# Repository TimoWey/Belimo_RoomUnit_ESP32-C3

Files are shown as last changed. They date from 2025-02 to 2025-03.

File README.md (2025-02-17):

# Belimo RoomUnit ESP32-C3

This project reads Temperature, Humidity, and CO2 levels from a Belimo Room Unit sensor using a Seeed XIAO ESP32-C3 and publishes the data via MQTT.

## Hardware Requirements

- Seeed XIAO ESP32-C3 board (https://wiki.seeedstudio.com/XIAO_ESP32C3_Getting_Started/)
- Belimo Room Unit sensor
- Power supply (USB or external)
- Connecting wires

## Wiring

Connect the Belimo Room Unit to the ESP32-C3 as follows:

| Belimo Signal | ESP32-C3 Pin | ADC Channel |
|---|---|---|
| Temperature | GPIO2/A2 | ADC2 |
| Humidity | GPIO3/A3 | ADC3 |
| CO2 | GPIO4/A4 | ADC4 |
| GND | GND | - |

## Software Setup

### Prerequisites

1. Install ESP-IDF (Espressif IoT Development Framework)
2. Clone this repository
3. Navigate to the project directory

### Configuration

1. Configure the WiFi and other project settings using:
```bash
idf.py menuconfig
```

Under "Example Configuration":
- Set WiFi SSID
- Set WiFi Password

2. Update the following parameters in `main/main.c` according to your setup:
```c
#define MQTT_BROKER_URL "mqtt://192.168.0.68"    // Your MQTT broker IP/hostname
#define MQTT_PORT 1883                           // Your MQTT broker port
#define MQTT_TOPIC_TEMP "sensors/temperature_2"  // MQTT topic for temperature
#define MQTT_TOPIC_HUMIDITY "sensors/humidity_2" // MQTT topic for humidity
#define MQTT_TOPIC_CO2 "sensors/co2_2"          // MQTT topic for CO2
```

3. Optional settings you can modify:
- `LED_BLINK_ENABLED`: Set to `true` to enable status LED blinking
- `FILTER_SIZE`: Number of samples for reading averaging (default: 16)
- `SAMPLE_INTERVAL`: Time between samples in ms (default: 100)

4. Flash to your device:

```bash
idf.py -p [PORT] flash
```
```bash
idf.py monitor
```

## MQTT Data Format

The device publishes JSON data to three topics:

1. Temperature (sensors/temperature):

```json
{"voltage": 1.23, "temperature": 24.5}
```

2. Humidity (sensors/humidity):

```json
{"voltage": 1.23, "humidity": 50.0}
```

3. CO2 (sensors/co2):

```json
{"voltage": 1.45, "humidity": 45.2}
```

{"voltage": 1.67, "co2": 850.0}

## Sensor Ranges

- Temperature: 0°C to 50°C
- Humidity: 0% to 100%
- CO2: 0 to 2000 ppm

## LED Indicator

The onboard LED (GPIO10) can be enabled for status indication by setting `LED_BLINK_ENABLED` to `true` in the code.

## Troubleshooting

1. If the device fails to connect to WiFi:
   - Check your WiFi credentials
   - Ensure the device is within range of your WiFi network
   - Monitor the serial output for connection status

2. If MQTT publishing fails:
   - Verify your MQTT broker is running
   - Check the broker URL and port
   - Ensure your network allows MQTT traffic

## License

This project is open-source and available under the MIT License.

## Contributing

Feel free to submit issues and pull requests to improve this project.

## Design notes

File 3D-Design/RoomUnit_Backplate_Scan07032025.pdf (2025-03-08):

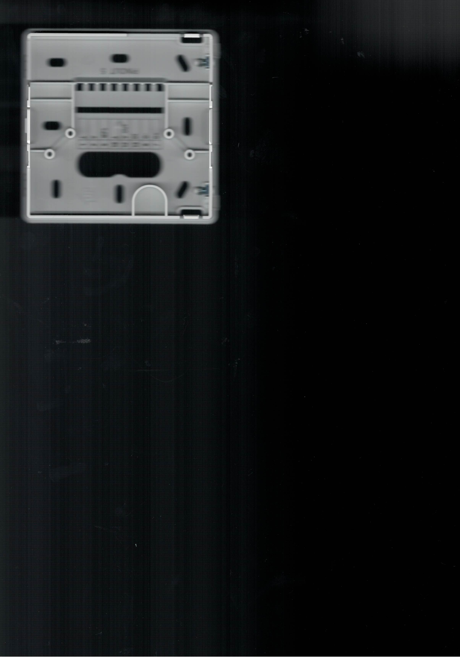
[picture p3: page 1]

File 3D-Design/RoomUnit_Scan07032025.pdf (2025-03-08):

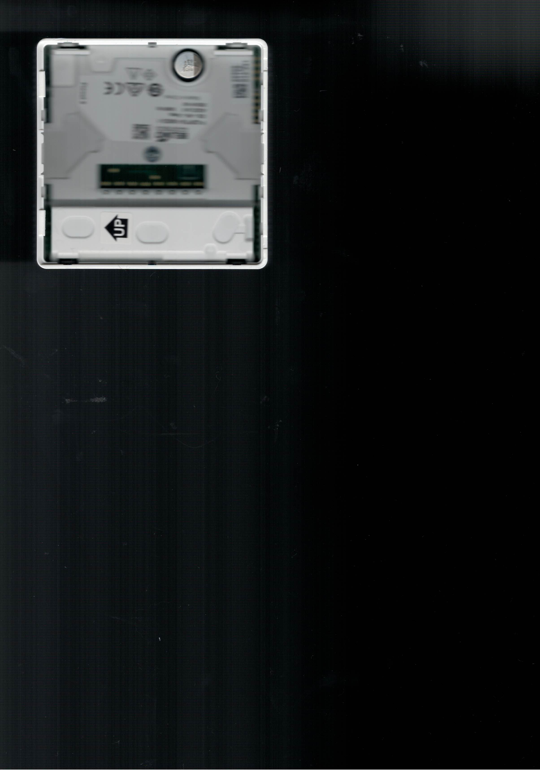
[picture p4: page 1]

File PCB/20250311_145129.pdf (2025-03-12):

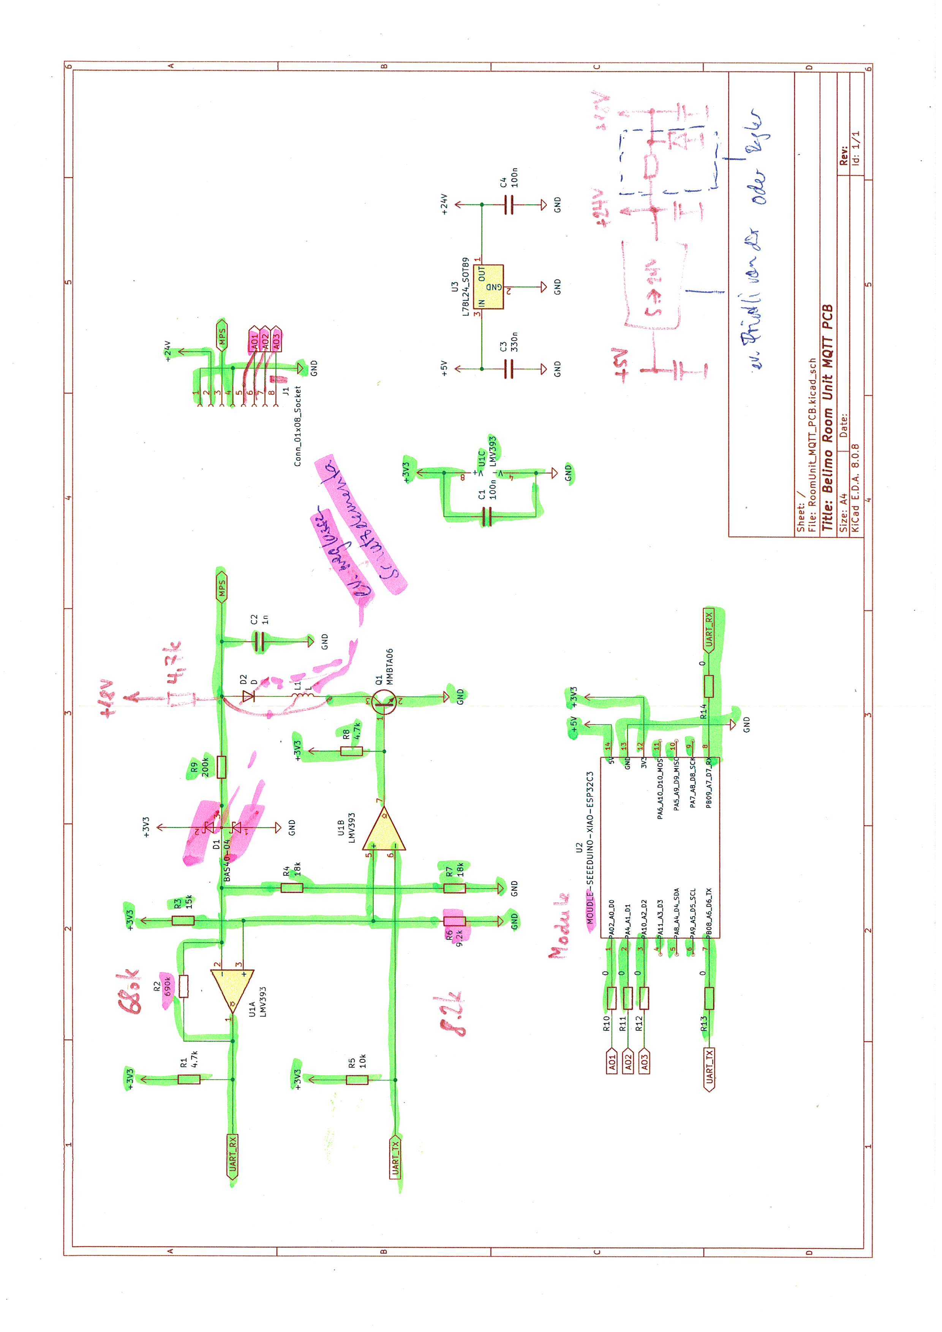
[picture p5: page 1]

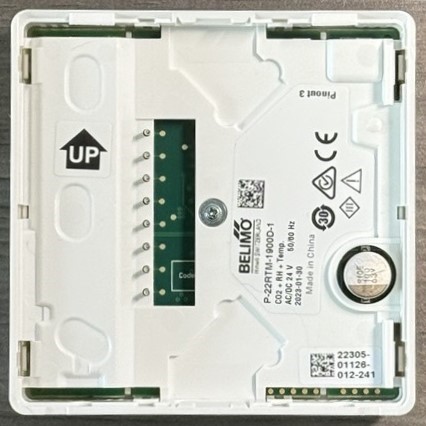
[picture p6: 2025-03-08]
3D-Design/Image.jpg

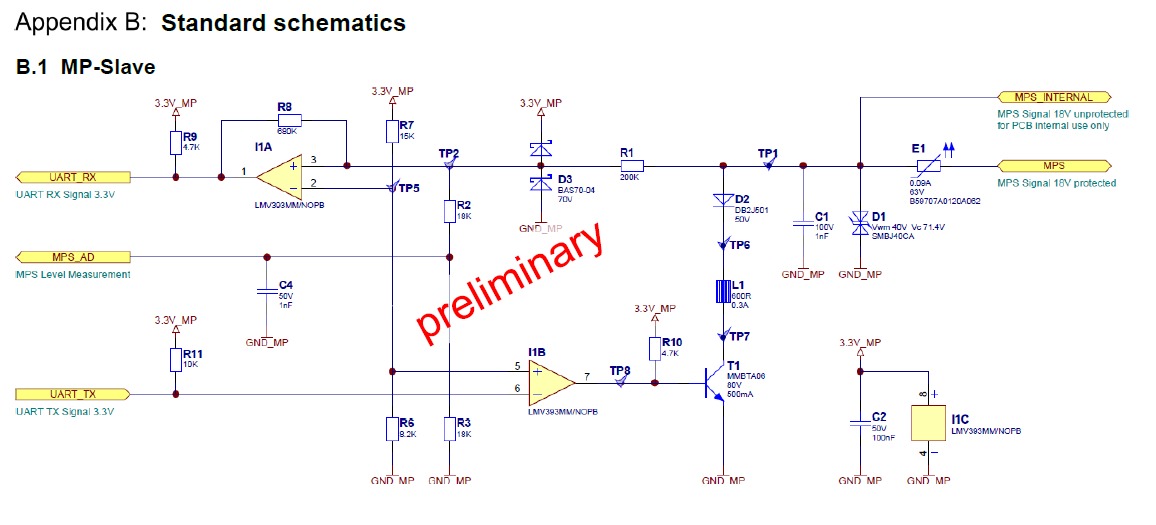
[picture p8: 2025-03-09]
PCB/Belimo_MP-Schematic.jpeg

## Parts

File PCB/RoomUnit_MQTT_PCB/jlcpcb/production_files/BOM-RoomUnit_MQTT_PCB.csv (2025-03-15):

Comment | Designator | Footprint | LCSC | Quantity
1M | R7 | R_0805_2012Metric_Pad1.20x1.40mm_HandSolder | C107700 | 1
200k | R9 | R_0805_2012Metric_Pad1.20x1.40mm_HandSolder | C114562 | 1
10u | L1 | L_Chilisin_BMRA00040420 | C133195 | 1
8.2k | R6 | R_0805_2012Metric_Pad1.20x1.40mm_HandSolder | C137399 | 1
1.6k | R16 | R_0805_2012Metric_Pad1.20x1.40mm_HandSolder | C137580 | 1
33k | R15 | R_0805_2012Metric_Pad1.20x1.40mm_HandSolder | C141696 | 1
1n | C2 | C_0805_2012Metric_Pad1.18x1.45mm_HandSolder | C15177 | 1
1.2k | R17 | R_0805_2012Metric_Pad1.20x1.40mm_HandSolder | C17379 | 1
10k | R18,R19,R20,R5 | R_0805_2012Metric_Pad1.20x1.40mm_HandSolder | C17414 | 4
15k | R3 | R_0805_2012Metric_Pad1.20x1.40mm_HandSolder | C17475 | 1
0 | R13,R14 | R_0805_2012Metric_Pad1.20x1.40mm_HandSolder | C17477 | 2
4.7k | R1,R4,R8 | R_0805_2012Metric_Pad1.20x1.40mm_HandSolder | C17673 | 3
680k | R2 | R_0805_2012Metric_Pad1.20x1.40mm_HandSolder | C17797 | 1
1u | C3 | C_1206_3216Metric | C1848 | 1
BZX84C18 | D1 | SOT-23 | C19077473 | 1
MMBTA06 | Q1 | SOT-23 | C20069139 | 1
100n | C1,C5 | C_0805_2012Metric_Pad1.18x1.45mm_HandSolder | C28233 | 2
4.7u | C4 | C_1206_3216Metric | C29823 | 1
TLV61046ADB | U2 | SOT-23-6 | C464815 | 1
LMV393 | U1 | SOIC-8_3.9x4.9mm_P1.27mm | C7984 | 1

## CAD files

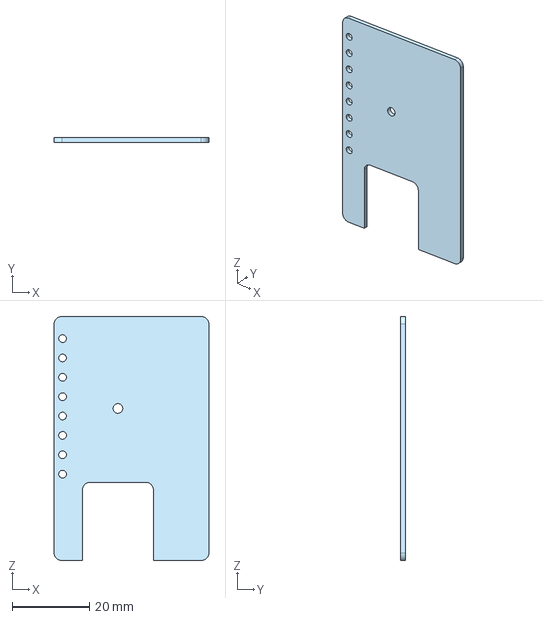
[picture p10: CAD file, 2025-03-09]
3D-Design/Part Studio 1 - PCB.step
40.0 x 1.20 x 63.0 mm

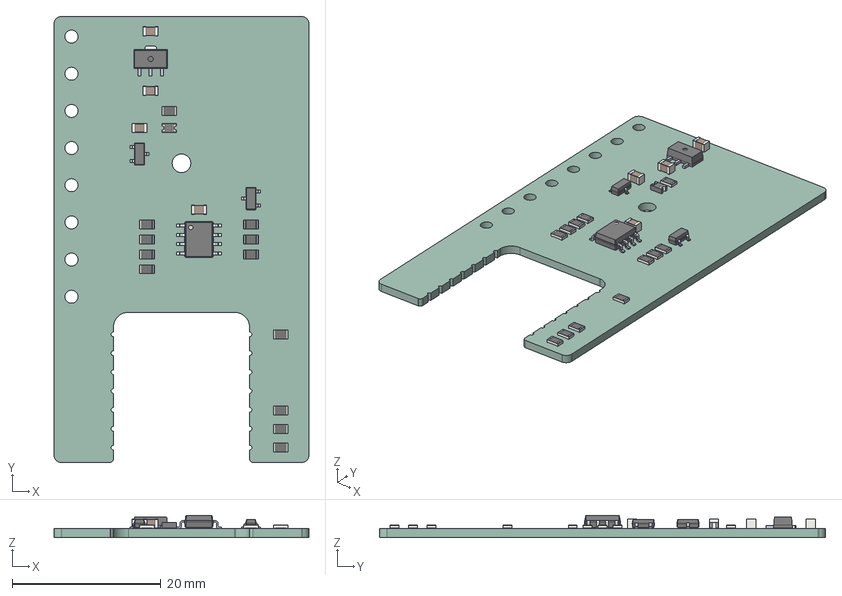
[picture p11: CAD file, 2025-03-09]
PCB/RoomUnit_MQTT_PCB/RoomUnit_MQTT_PCB.step
34.3 x 60.0 x 3.00 mm
R_0805_2012Metric x 12
C_0805_2012Metric x 4
SOT_23 x 2
D_0805
CQ assembly
SOIC_8_39x49mm_P127mm
RoomUnit_MQTT_PCB_PCB

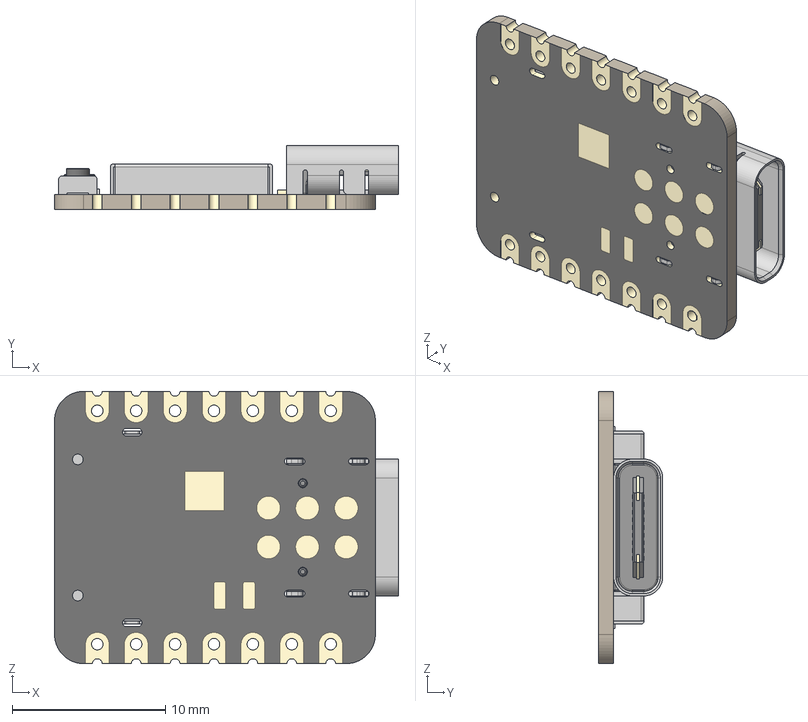
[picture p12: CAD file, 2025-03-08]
3D-Design/Seeed Studio XIAO-ESP32-C3.step
22.5 x 4.21 x 17.8 mm
BOSS-EXTRUDE14_8_
BOSS-EXTRUDE7_4_
BOSS-EXTRUDE7_3_
BOSS-EXTRUDE14_4_
BOSS-EXTRUDE14_2_
BOSS-EXTRUDE14_11_
BOSS-EXTRUDE7_7_
BOSS-EXTRUDE14_9_
BOSS-EXTRUDE14_3_
BOSS-EXTRUDE14_7_
MIRROR2
BOSS-EXTRUDE14_5_
BOSS-EXTRUDE14_12_
BOSS-EXTRUDE7_8_
BOSS-EXTRUDE7_1_
BOSS-EXTRUDE14_10_
BOSS-EXTRUDE7_9_
BOSS-EXTRUDE14_6_
BOSS-EXTRUDE14_1_
BOSS-EXTRUDE7_6_
BOSS-EXTRUDE7_2_
CUT-EXTRUDE5
BOSS-EXTRUDE7_5_
U.FL Connector v1
Button (1) x 2
Shield

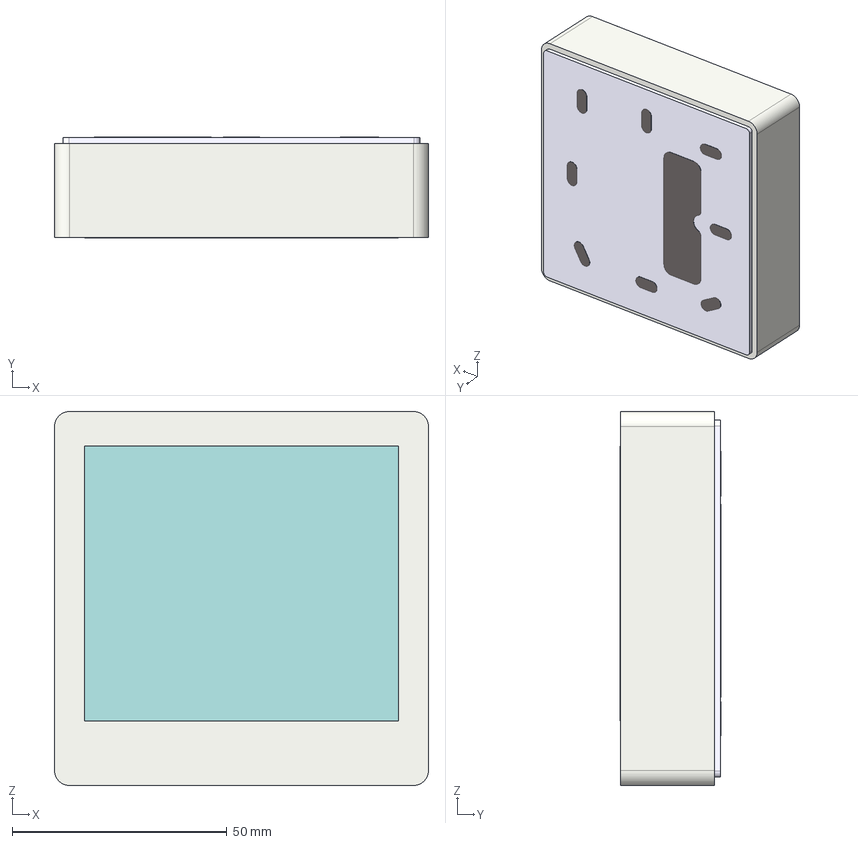
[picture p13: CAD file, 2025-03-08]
3D-Design/P-22RTM-1900D-11.stp
87.0 x 23.5 x 87.0 mm

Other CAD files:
3D-Design/PCB_MOCKUP_v1.3.step

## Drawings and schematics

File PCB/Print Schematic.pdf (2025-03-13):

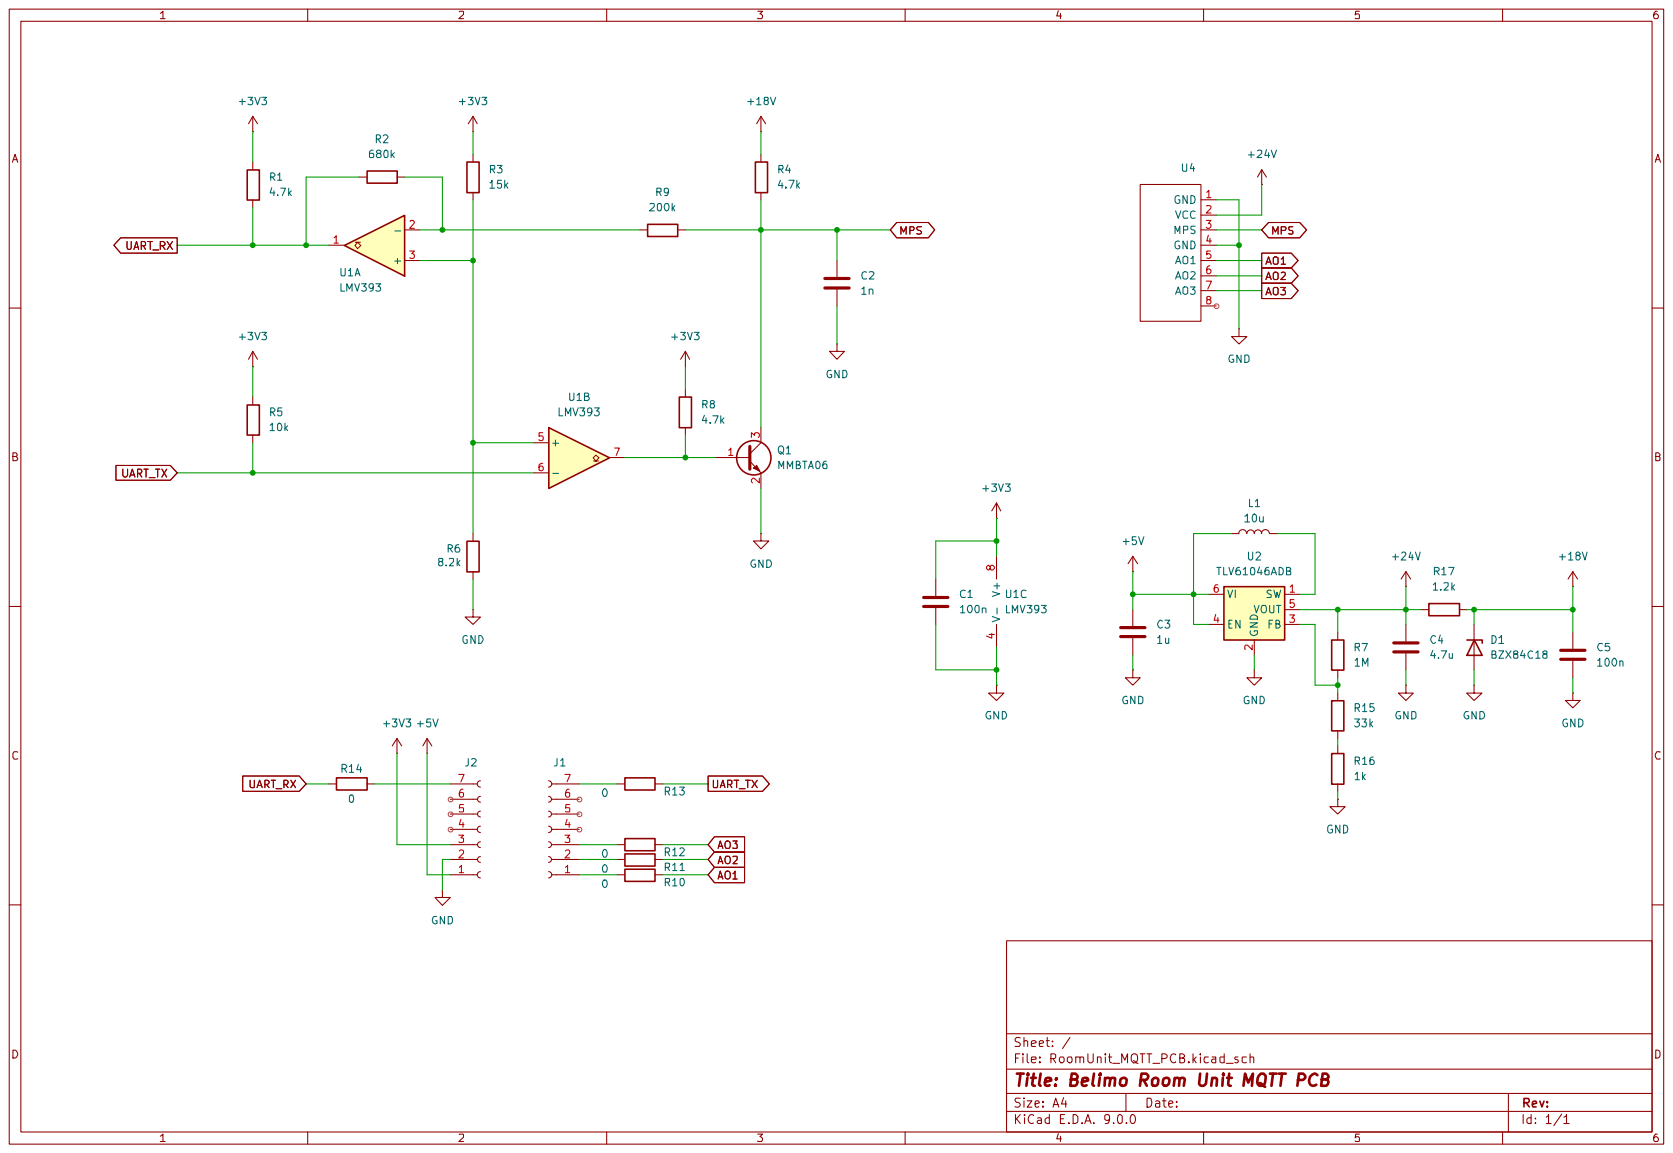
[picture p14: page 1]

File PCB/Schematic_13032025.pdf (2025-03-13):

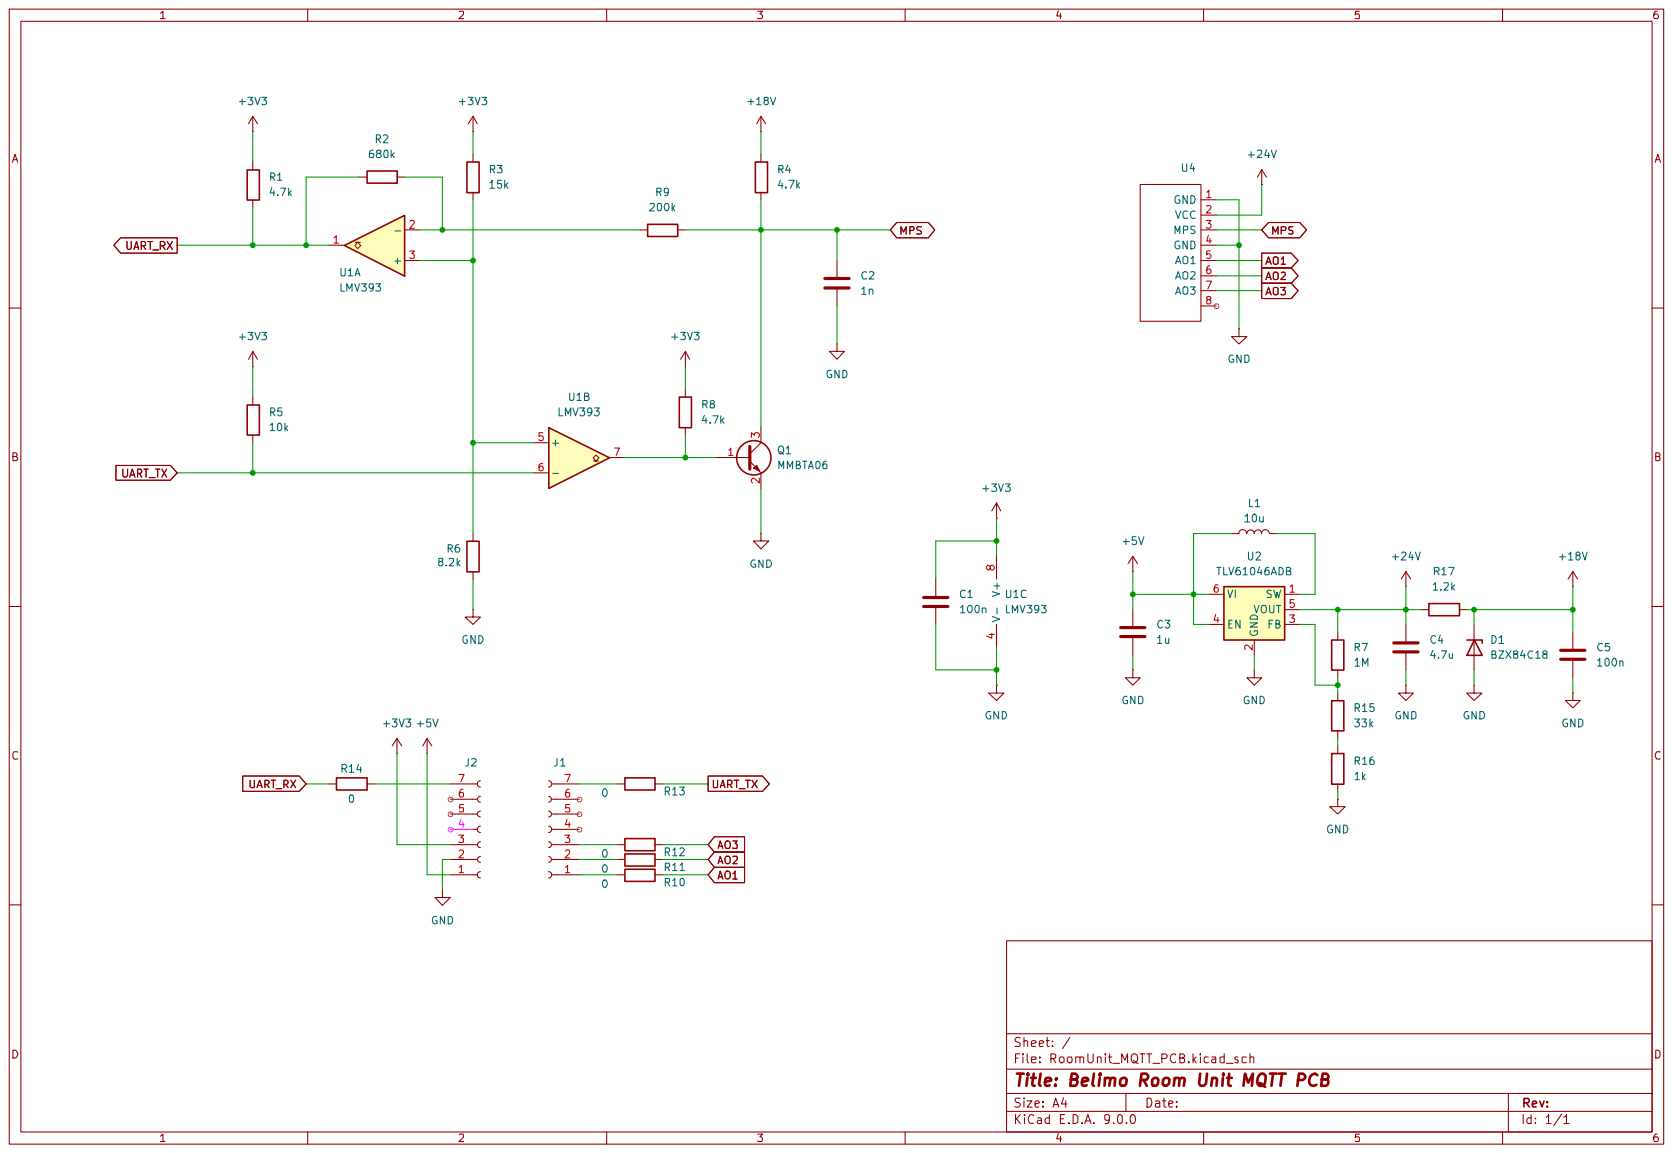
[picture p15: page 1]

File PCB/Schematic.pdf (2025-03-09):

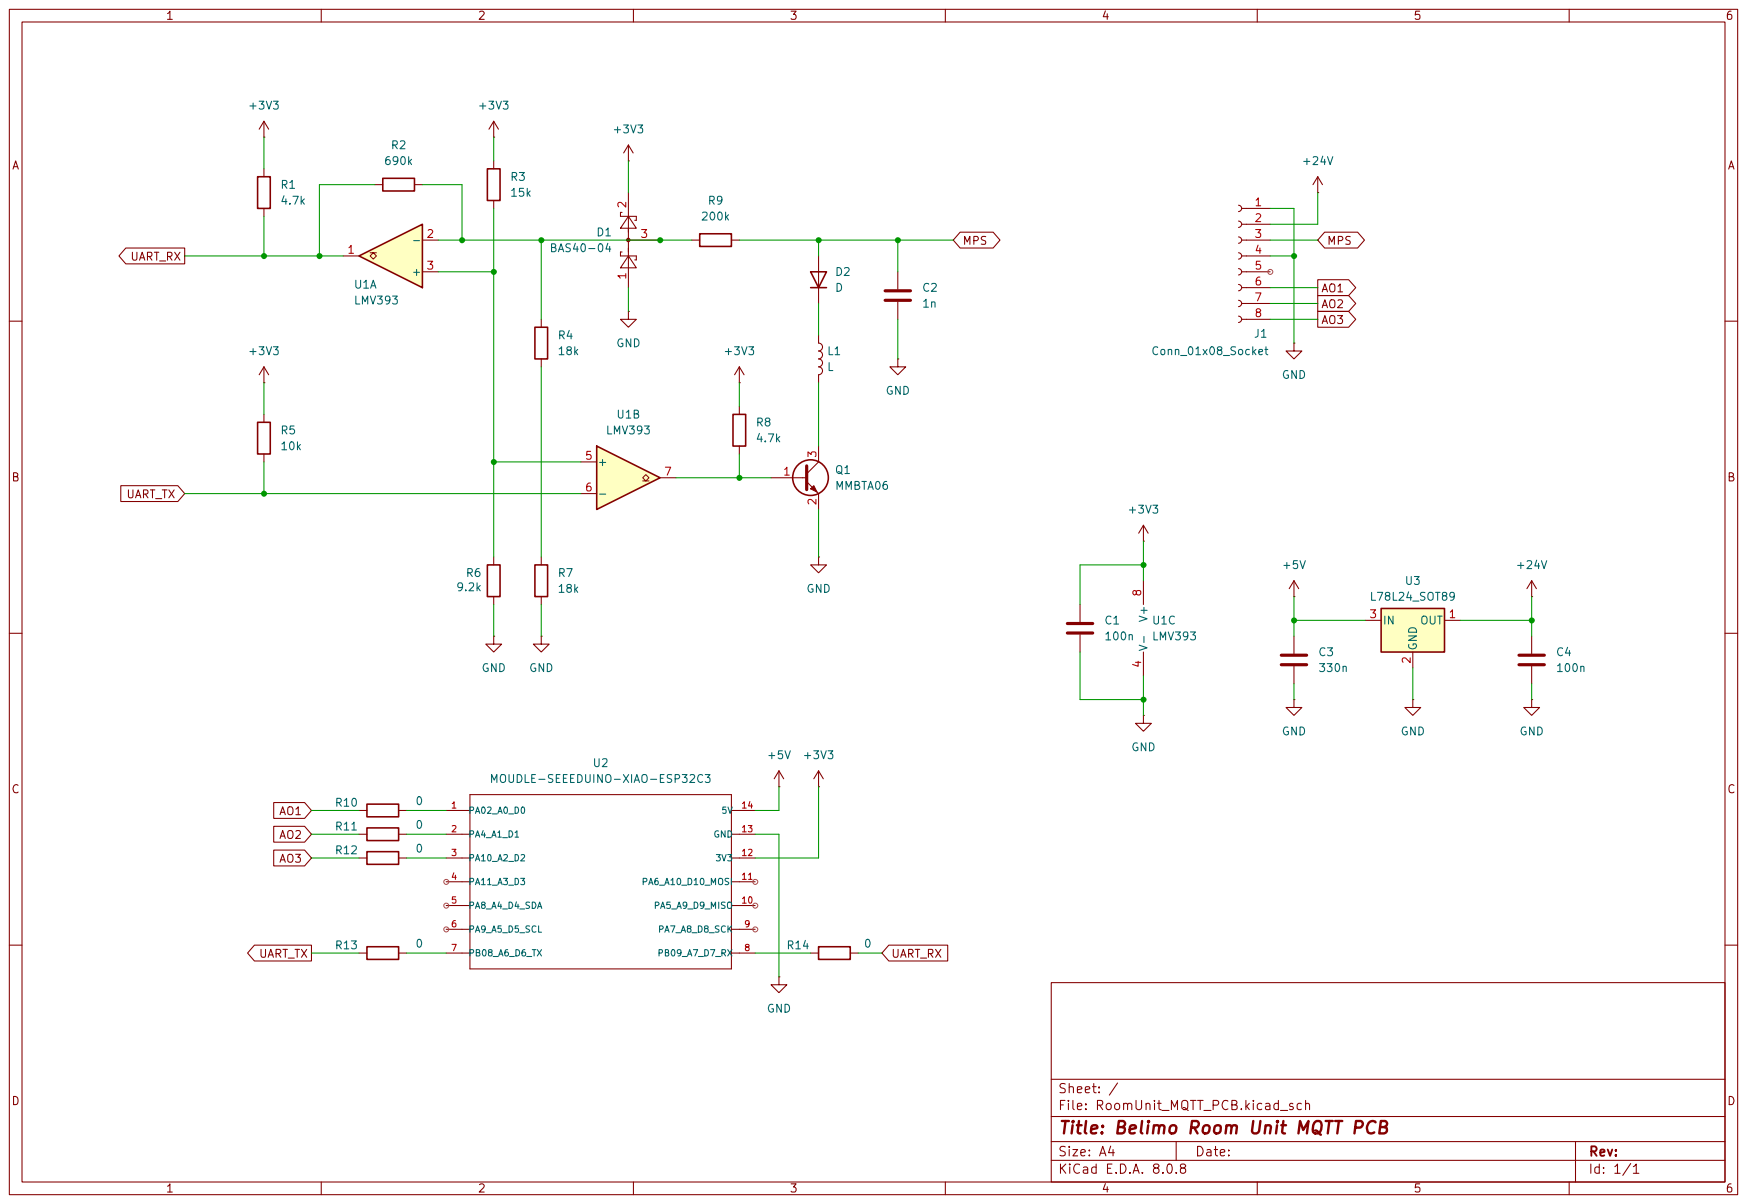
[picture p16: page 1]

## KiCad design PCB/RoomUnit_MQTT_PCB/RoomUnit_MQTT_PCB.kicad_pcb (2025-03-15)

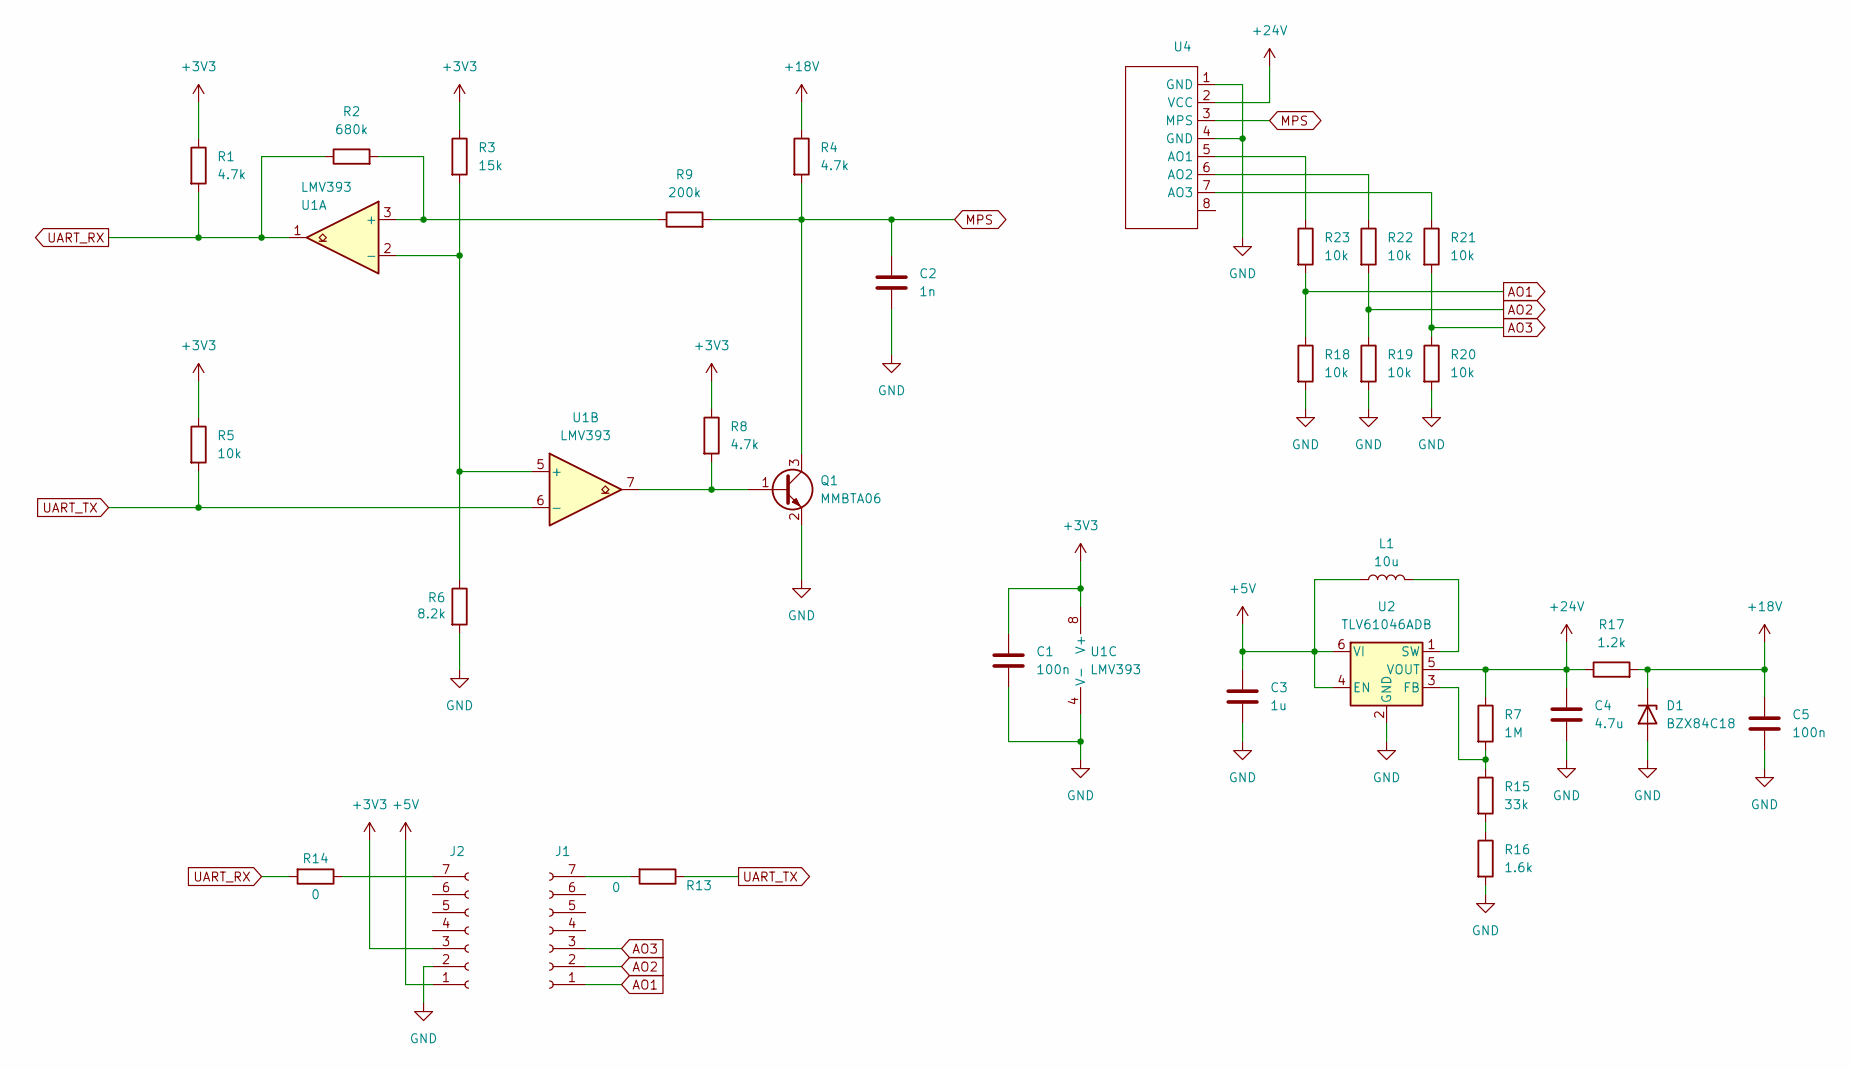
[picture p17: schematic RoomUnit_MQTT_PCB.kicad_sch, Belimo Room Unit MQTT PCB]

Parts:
C1, C5: 100n; C_0805_2012Metric_Pad1.18x1.45mm_HandSolder
C2: 1n; C_0805_2012Metric_Pad1.18x1.45mm_HandSolder
C3: 1u; C_1206_3216Metric
C4: 4.7u; C_1206_3216Metric
D1: BZX84C18; SOT-23
J1, J2: Conn_01x07_Socket; XIAO_ESP32-C3_Custom_Connector
L1: 10u; L_Chilisin_BMRA00040420
Q1: MMBTA06; SOT-23
R1, R4, R8: 4.7k; R_0805_2012Metric_Pad1.20x1.40mm_HandSolder
R2: 680k; R_0805_2012Metric_Pad1.20x1.40mm_HandSolder
R3: 15k; R_0805_2012Metric_Pad1.20x1.40mm_HandSolder
R5, R18, R19, R20, R21, R22, R23: 10k; R_0805_2012Metric_Pad1.20x1.40mm_HandSolder
R6: 8.2k; R_0805_2012Metric_Pad1.20x1.40mm_HandSolder
R7: 1M; R_0805_2012Metric_Pad1.20x1.40mm_HandSolder
R9: 200k; R_0805_2012Metric_Pad1.20x1.40mm_HandSolder
R13, R14: 0; R_0805_2012Metric_Pad1.20x1.40mm_HandSolder
R15: 33k; R_0805_2012Metric_Pad1.20x1.40mm_HandSolder
R16: 1.6k; R_0805_2012Metric_Pad1.20x1.40mm_HandSolder
R17: 1.2k; R_0805_2012Metric_Pad1.20x1.40mm_HandSolder
U1: LMV393; SOIC-8_3.9x4.9mm_P1.27mm
U2: TLV61046ADB; SOT-23-6
U4: RoomUnit_Connector_5mm

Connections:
+3V3: C1.1, J2.3, R1.1, R3.1, R5.1, R8.1, U1.8 (V+)
+5V: C3.1, J2.1, L1.1, U2.4 (EN), U2.6 (VI)
+18V: C5.1, D1.3 (K), R4.1, R17.2
+24V: C4.1, R7.1, R17.1, U2.5 (VOUT), U4.2 (VCC)
AO1: J1.1, R18.1, R23.2
AO2: J1.2, R19.1, R22.2
AO3: J1.3, R20.1, R21.2
GND: C1.2, C2.2, C3.2, C4.2, C5.2, D1.1 (A), J2.2, Q1.2 (E), R6.2, R16.2, R18.2, R19.2, R20.2, U1.4 (V-), U2.2 (GND), U4.1 (GND), U4.4 (GND)
MPS: C2.1, Q1.3 (C), R4.2, R9.2, U4.3 (MPS)
unnamed: J1.7, R13.2
unnamed: J2.7, R14.1
unnamed: Q1.1 (B), R8.2, U1.7
unnamed: R15.2, R16.1
unnamed: R2.2, R9.1, U1.3 (+)
unnamed: R3.2, R6.1, U1.2 (-), U1.5 (+)
unnamed: R7.2, R15.1, U2.3 (FB)
unnamed: L1.2, U2.1 (SW)
unnamed: R23.1, U4.5 (AO1)
unnamed: R22.1, U4.6 (AO2)
unnamed: R21.1, U4.7 (AO3)
UART_RX: R1.2, R2.1, R14.2, U1.1
UART_TX: R5.2, R13.1, U1.6 (-)

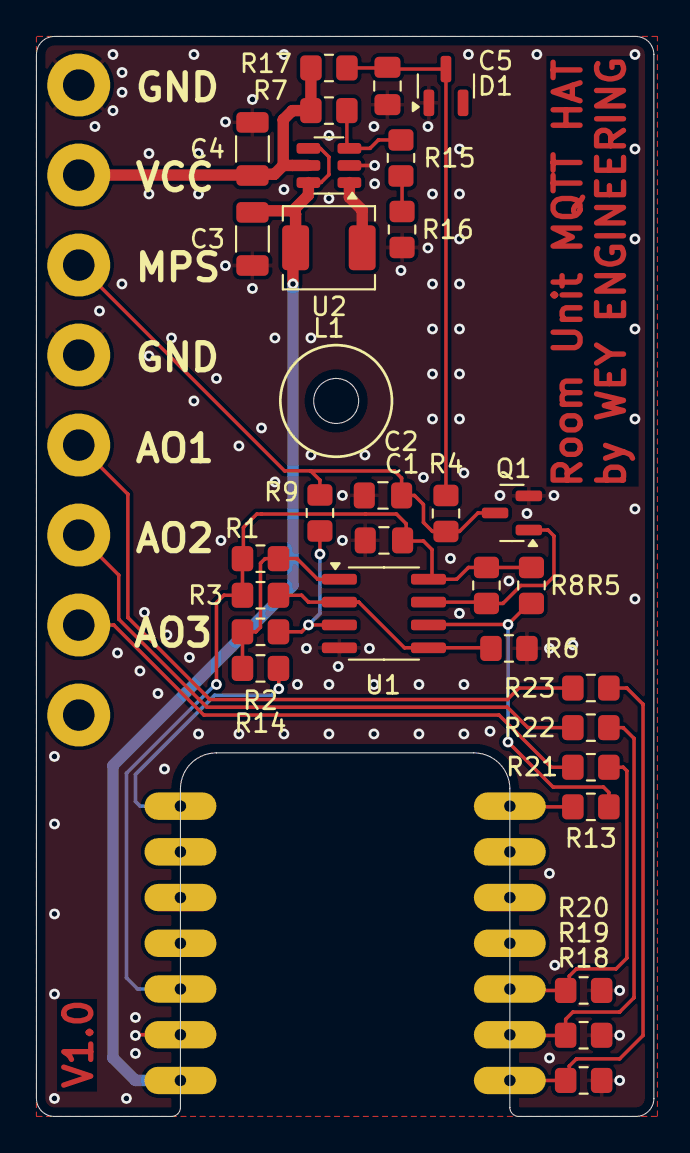
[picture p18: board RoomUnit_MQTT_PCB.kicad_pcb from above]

Board: 2 copper layers, 34.3 x 60.0 mm, 33 parts (0 on the bottom side), 22 nets.

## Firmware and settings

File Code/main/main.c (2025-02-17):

/*
 * @file main.c
 * @brief Main file for the ESP32 microcontroller
 *
 * This file contains the main entry point for the ESP32 microcontroller
 * and the initialization and configuration of the WiFi and MQTT clients.
 */

#include <stdbool.h>
#include <stdio.h>
#include "driver/gpio.h"
#include "esp_adc/adc_oneshot.h"
#include "esp_adc/adc_cali.h"
#include "esp_adc/adc_cali_scheme.h"
#include "freertos/FreeRTOS.h" // IWYU pragma: keep
#include "freertos/task.h"
#include "esp_wifi.h"
#include "esp_event.h"
#include "hal/adc_types.h"
#include "nvs_flash.h"
#include "mqtt_client.h"
#include "esp_log.h"

#define LED_BLINK_ENABLED false            // Set to TRUE to enable LED blinking
#define LED_GPIO GPIO_NUM_10               // Set your LED GPIO pin
#define TEMP_ADC_CHANNEL ADC_CHANNEL_2     // Set your temperature ADC channel
#define HUMIDITY_ADC_CHANNEL ADC_CHANNEL_3 // Set your humidity ADC channel
#define CO2_ADC_CHANNEL ADC_CHANNEL_4      // Set your CO2 ADC channel
#define ADC_RAW_MAX 4095                   // 12-bit ADC (2^12 - 1)
#define VOLTAGE_MIN 0                      // mV at 0°C, 0% Humidity, 0 ppm CO2
#define VOLTAGE_MAX 2500                   // mV at 50°C, 100% Humidity, 1000 ppm CO2
#define TEMP_MIN 0.0f                      // Temperature at VOLTAGE_MIN
#define TEMP_MAX 50.0f                     // Temperature at VOLTAGE_MAX
#define HUMIDITY_MIN 0.0f                  // Humidity at VOLTAGE_MIN
#define HUMIDITY_MAX 100.0f                // Humidity at VOLTAGE_MAX
#define CO2_MIN 0.0f                       // ppm at VOLTAGE_MIN
#define CO2_MAX 2000.0f                    // ppm at VOLTAGE_MAX

// Filter settings
#define FILTER_SIZE 16      // Increased from 1 to 16 samples
#define SAMPLE_INTERVAL 100 // Decreased to 10ms between samples

// Add these definitions
#define WIFI_SSID CONFIG_EXAMPLE_WIFI_SSID       // Set your WiFi SSID
#define WIFI_PASS CONFIG_EXAMPLE_WIFI_PASSWORD   // Set your WiFi password
#define MQTT_BROKER_URL "mqtt://192.168.0.68"    // Set your MQTT broker URL
#define MQTT_PORT 1883                           // Set your MQTT broker port
#define MQTT_TOPIC_TEMP "sensors/temperature_2"  // Set your MQTT topic for temperature
#define MQTT_TOPIC_HUMIDITY "sensors/humidity_2" // Set your MQTT topic for humidity
#define MQTT_TOPIC_CO2 "sensors/co2_2"           // Set your MQTT topic for CO2

// Constants for ADC configuration
#define ADC_UNIT ADC_UNIT_1
#define ADC_ATTEN ADC_ATTEN_DB_12
#define ADC_BITWIDTH ADC_BITWIDTH_12

// WiFi connection timeout settings
#define WIFI_RETRY_COUNT 10
#define WIFI_RETRY_DELAY_MS 1000

// MQTT settings
#define MQTT_KEEPALIVE_SEC 15
#define MQTT_QOS 1
#define MQTT_RETAIN 0

// Task settings
#define TASK_STACK_SIZE_LED 2048
#define TASK_STACK_SIZE_SENSOR 4096
#define TASK_PRIORITY 5

static const char *TAG = "TEMP_SENSOR";
static esp_mqtt_client_handle_t mqtt_client = NULL;

// Add this structure to store sensor readings
typedef struct
{
    float temperature;
    float humidity;
    float co2;
} sensor_readings_t;

/**
 * @brief Get filtered voltage readings from ADC
 * @param adc1_handle ADC unit handle
 * @param cali_handle ADC calibration handle
 * @param channel ADC channel to read from
 * @return Filtered voltage value in mV
 */
float get_filtered_voltage(adc_oneshot_unit_handle_t adc1_handle, adc_cali_handle_t cali_handle, adc_channel_t channel)
{
    float sum = 0;

    // Take multiple readings
    for (int i = 0; i < FILTER_SIZE; i++)
    {
        int adc_raw;
        int voltage;
        ESP_ERROR_CHECK(adc_oneshot_read(adc1_handle, channel, &adc_raw));
        ESP_ERROR_CHECK(adc_cali_raw_to_voltage(cali_handle, adc_raw, &voltage));
        sum += voltage;
        vTaskDelay(pdMS_TO_TICKS(SAMPLE_INTERVAL));
    }
    return sum / FILTER_SIZE;
}

/**
 * @brief Task to blink onboard LED
 * @param pvParameters Task parameters (unused)
 */
void led_blink_task(void *pvParameters)
{
    while (1)
    {
        gpio_set_level(LED_GPIO, 1);
        vTaskDelay(500 / portTICK_PERIOD_MS);
        gpio_set_level(LED_GPIO, 0);
        vTaskDelay(500 / portTICK_PERIOD_MS);
    }
}

/**
 * @brief Wait for WiFi connection with timeout
 */
static void wait_for_wifi(void)
{
    int retry = 0;
    while (retry < WIFI_RETRY_COUNT)
    {
        wifi_ap_record_t ap_info;
        esp_err_t ret = esp_wifi_sta_get_ap_info(&ap_info);
        if (ret == ESP_OK)
        {
            ESP_LOGI(TAG, "WiFi connected successfully");
            return;
        }
        ESP_LOGI(TAG, "Waiting for WiFi connection... (%d/%d)",
                 retry + 1, WIFI_RETRY_COUNT);
        retry++;
        vTaskDelay(pdMS_TO_TICKS(WIFI_RETRY_DELAY_MS));
    }
    ESP_LOGE(TAG, "Failed to connect to WiFi!");
}

/**
 * @brief Initialize WiFi connection
 */
static void wifi_init(void)
{
    /* Initialize the network interface */
    ESP_ERROR_CHECK(esp_netif_init());
    ESP_ERROR_CHECK(esp_event_loop_create_default());
    esp_netif_create_default_wifi_sta();

    /* Initialize the WiFi driver */
    wifi_init_config_t cfg = WIFI_INIT_CONFIG_DEFAULT();
    ESP_ERROR_CHECK(esp_wifi_init(&cfg));

    /* Configure the WiFi connection */
    wifi_config_t wifi_config = {
        .sta = {
            .ssid = WIFI_SSID,
            .password = WIFI_PASS,
        },
    };

    ESP_LOGI(TAG, "Setting WiFi configuration...");
    ESP_ERROR_CHECK(esp_wifi_set_mode(WIFI_MODE_STA));
    ESP_ERROR_CHECK(esp_wifi_set_config(WIFI_IF_STA, &wifi_config));
    ESP_ERROR_CHECK(esp_wifi_start());
    ESP_ERROR_CHECK(esp_wifi_connect());

    wait_for_wifi();
}

/**
 * @brief MQTT event handler
 */
static void mqtt_event_handler(void *handler_args,
                               esp_event_base_t base,
                               int32_t event_id,
                               void *event_data)
{
    esp_mqtt_event_handle_t event = event_data;

    switch (event->event_id)
    {
    case MQTT_EVENT_CONNECTED:
        ESP_LOGI(TAG, "MQTT Connected to broker at %s", MQTT_BROKER_URL);
        break;
    case MQTT_EVENT_DISCONNECTED:
        ESP_LOGE(TAG, "MQTT Disconnected from broker. Will auto-reconnect...");
        break;
    case MQTT_EVENT_ERROR:
        ESP_LOGE(TAG, "MQTT Error Event");
        if (event->error_handle->error_type == MQTT_ERROR_TYPE_TCP_TRANSPORT)
        {
            ESP_LOGE(TAG, "Last error code reported from esp-tls: 0x%x",
                     event->error_handle->esp_tls_last_esp_err);
            ESP_LOGE(TAG, "Last tls stack error number: 0x%x",
                     event->error_handle->esp_tls_stack_err);
            ESP_LOGE(TAG, "Last captured errno : %d (%s)",
                     event->error_handle->esp_transport_sock_errno,
                     strerror(event->error_handle->esp_transport_sock_errno));
        }
        break;
    case MQTT_EVENT_BEFORE_CONNECT:
        ESP_LOGI(TAG, "MQTT Attempting connection to broker...");
        break;
    default:
        break;
    }
}

/**
 * @brief Initialize MQTT client
 */
static void mqtt_init(void)
{
    esp_mqtt_client_config_t mqtt_cfg = {
        .broker.address.uri = MQTT_BROKER_URL,
        .broker.address.port = MQTT_PORT,
        .session.keepalive = MQTT_KEEPALIVE_SEC,
    };

    ESP_LOGI(TAG, "Initializing MQTT client for broker %s:%d", MQTT_BROKER_URL, MQTT_PORT);
    mqtt_client = esp_mqtt_client_init(&mqtt_cfg);
    if (mqtt_client == NULL)
    {
        ESP_LOGE(TAG, "Failed to initialize MQTT client!");
        return;
    }

    ESP_ERROR_CHECK(esp_mqtt_client_register_event(mqtt_client, ESP_EVENT_ANY_ID, mqtt_event_handler, NULL));
    ESP_ERROR_CHECK(esp_mqtt_client_start(mqtt_client));
}

/**
 * @brief Task to read sensor values and publish to MQTT
 * @param pvParameters Pointer to ADC handle
 */
void sensor_reading_task(void *pvParameters)
{
    adc_oneshot_unit_handle_t adc1_handle = *((adc_oneshot_unit_handle_t *)pvParameters);

    adc_cali_handle_t adc1_cali_handle = NULL;
    adc_cali_curve_fitting_config_t cali_config = {
        .unit_id = ADC_UNIT,
        .atten = ADC_ATTEN,
        .bitwidth = ADC_BITWIDTH,
    };
    ESP_ERROR_CHECK(adc_cali_create_scheme_curve_fitting(&cali_config,
                                                         &adc1_cali_handle));

    while (1)
    {
        // Get readings for all sensors
        float temp_voltage = get_filtered_voltage(adc1_handle, adc1_cali_handle,
                                                  TEMP_ADC_CHANNEL);
        float humidity_voltage = get_filtered_voltage(adc1_handle, adc1_cali_handle,
                                                      HUMIDITY_ADC_CHANNEL);
        float co2_voltage = get_filtered_voltage(adc1_handle, adc1_cali_handle,
                                                 CO2_ADC_CHANNEL);

        // Convert voltages to sensor values
        float temperature = (temp_voltage * (TEMP_MAX - TEMP_MIN)) / VOLTAGE_MAX + TEMP_MIN;
        float humidity = (humidity_voltage * (HUMIDITY_MAX - HUMIDITY_MIN)) / VOLTAGE_MAX + HUMIDITY_MIN;
        float co2 = (co2_voltage * (CO2_MAX - CO2_MIN)) / VOLTAGE_MAX + CO2_MIN;

        // Create JSON strings for MQTT
        char temp_data[100], humidity_data[100], co2_data[100];
        snprintf(temp_data, sizeof(temp_data),
                 "{\"voltage\":%.2f,\"temperature\":%.1f}",
                 temp_voltage / 1000.0f, temperature);
        snprintf(humidity_data, sizeof(humidity_data),
                 "{\"voltage\":%.2f,\"humidity\":%.1f}",
                 humidity_voltage / 1000.0f, humidity);
        snprintf(co2_data, sizeof(co2_data),
                 "{\"voltage\":%.2f,\"co2\":%.1f}",
                 co2_voltage / 1000.0f, co2);

        // Publish to MQTT
        if (mqtt_client != NULL)
        {
            esp_mqtt_client_publish(mqtt_client, MQTT_TOPIC_TEMP, temp_data, 0, 1, 0);
            esp_mqtt_client_publish(mqtt_client, MQTT_TOPIC_HUMIDITY, humidity_data, 0, 1, 0);
            esp_mqtt_client_publish(mqtt_client, MQTT_TOPIC_CO2, co2_data, 0, 1, 0);

            // Print readings
            ESP_LOGI(TAG, "Temperature: %.1f°C, Humidity: %.1f%%, CO2: %.1f ppm",
                     temperature, humidity, co2);
        }
    }
}

/**
 * @brief Application main entry point
 */
void app_main(void)
{
    // Initialize NVS
    esp_err_t ret = nvs_flash_init();
    if (ret == ESP_ERR_NVS_NO_FREE_PAGES || ret == ESP_ERR_NVS_NEW_VERSION_FOUND)
    {
        ESP_ERROR_CHECK(nvs_flash_erase());
        ret = nvs_flash_init();
    }
    ESP_ERROR_CHECK(ret);

    // Initialize WiFi
    wifi_init();

    // Initialize MQTT
    mqtt_init();

    // Configure LED GPIO
    esp_rom_gpio_pad_select_gpio(LED_GPIO);
    gpio_set_direction(LED_GPIO, GPIO_MODE_OUTPUT);

    // ADC Init
    adc_oneshot_unit_handle_t adc1_handle;
    adc_oneshot_unit_init_cfg_t init_config1 = {
        .unit_id = ADC_UNIT,
        .ulp_mode = ADC_ULP_MODE_DISABLE,
    };
    ESP_ERROR_CHECK(adc_oneshot_new_unit(&init_config1, &adc1_handle));

    // ADC Config for all channels
    adc_oneshot_chan_cfg_t config = {
        .atten = ADC_ATTEN,
        .bitwidth = ADC_BITWIDTH,
    };
    ESP_ERROR_CHECK(adc_oneshot_config_channel(adc1_handle, TEMP_ADC_CHANNEL, &config));
    ESP_ERROR_CHECK(adc_oneshot_config_channel(adc1_handle, HUMIDITY_ADC_CHANNEL, &config));
    ESP_ERROR_CHECK(adc_oneshot_config_channel(adc1_handle, CO2_ADC_CHANNEL, &config));

    // Create tasks
    if (LED_BLINK_ENABLED)
    {
        xTaskCreate(led_blink_task, "led_blink_task",
                    TASK_STACK_SIZE_LED, NULL, TASK_PRIORITY, NULL);
    }

    xTaskCreate(sensor_reading_task, "sensor_reading_task",
                TASK_STACK_SIZE_SENSOR, &adc1_handle, TASK_PRIORITY, NULL);

    // Main task can now sleep
    while (1)
    {
        vTaskDelay(pdMS_TO_TICKS(1000));
    }
}

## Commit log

2025-02-17 Squashed commit of the following:
    commit c27bc66c1dc90af4e393e254ebacadaf945d637d
    Author: Timää <timo@ritawey.ch>
    Date: Mon Feb 17 20:25:50 2025 +0100
    removed default state logging mqtt
    commit 88ae49d116315932d22b60c2f9d53f3f696779f4
    Author: Timää <timo@ritawey.ch>
    Date: Mon Feb 17 20:11:37 2025 +0100
    fixed some errors - code beautify
    commit bb3d3542cec92b369a92da1bc7e8fc15c5b1077c
    Author: Timää <timo@ritawey.ch>
    Date: Sat Jan 18 17:17:15 2025 +0100
    now reading temp, hum and co2
    commit bf2a2f2390afafda3081d314b8184ed6662ec397
    Author: Timää <timo@ritawey.ch>
    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
    [main.c]
2025-02-17 readme esp32 link added
2025-03-08 3D PCB Print 1
    [P-22RTM-1900D-11.stp, Part Studio 1 - PCB.step, Seeed Studio XIAO-ESP32-C3.step]
2025-03-09 PCB outline done
    [PCB_MOCKUP_v1.3.step, Part Studio 1 - PCB.step, RoomUnit_MQTT_PCB.kicad_pcb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]
2025-03-09 pcb progress
    [RoomUnit_MQTT_PCB.kicad_pcb, RoomUnit_MQTT_PCB.kicad_sch, RoomUnit_MQTT_PCB.step]
2025-03-09 pcb export
    [RoomUnit_MQTT_PCB.kicad_pcb, RoomUnit_MQTT_PCB.step]
2025-03-12 applied schematic changes (wip)
    [RoomUnit_MQTT_PCB.kicad_pcb, RoomUnit_MQTT_PCB.kicad_sch]
2025-03-12 PCB improvements
    [RoomUnit_MQTT_PCB.kicad_pcb, RoomUnit_MQTT_PCB.kicad_sch]
2025-03-13 schematic updated 18V
    [RoomUnit_MQTT_PCB.kicad_pcb, RoomUnit_MQTT_PCB.kicad_sch]
2025-03-13 SChematic update - PCB almost done
    [RoomUnit_MQTT_PCB.kicad_pcb, RoomUnit_MQTT_PCB.kicad_sch]
2025-03-13 added all jlc components
    [BOM-RoomUnit_MQTT_PCB.csv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]
2025-03-15 Spannungsteiler AOx
    [RoomUnit_MQTT_PCB.kicad_pcb, RoomUnit_MQTT_PCB.kicad_sch]
2025-03-15 3D assembly
    [RoomUnit_MQTT_PCB.kicad_pcb]
2025-03-15 DRC passed
    [RoomUnit_MQTT_PCB.kicad_pcb]
2025-03-15 fixed placement and package
    [BOM-RoomUnit_MQTT_PCB.csv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]

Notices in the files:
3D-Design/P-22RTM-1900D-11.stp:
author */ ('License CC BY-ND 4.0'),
